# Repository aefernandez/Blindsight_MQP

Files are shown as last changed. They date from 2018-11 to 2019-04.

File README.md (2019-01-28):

# Blindsight MQP

This repository hosts the code for the Blindsight MQP '19. Blindsight is an assistive navigation for the blind. It uses ultrasonic sensors mounted on a pair of 3D printed glasses to detect head-level objects. The device communicates with two vibrating modules using Nordic Semi NRF24 communication modules. The vibrating modules are wrist-worn devices that contain vibrating motors to give an indication of the distance to nearby obstacles. 

MQP - Major Qualifying Project 
Worcester Polytechnic Institute (WPI)

## Getting Started

Visit the Blindsight website and follow the instructions to get started on building your own prototype.

### Prerequisites

In order to program your prototype you'll need to install the Arduino IDE and drivers. The code is written for the ATmega328 platform (UNO, Nano, Mini).

### Installing

Upon downloading the files, place the Blindsight_Library folder inside the Arduino->libraries folder. This will install the Blindsight_Library in your Arduino environment. 

## Authors

* Alan Fernandez      - aefernandez@wpi.edu
* Aatreya Chakravarti - achakravarti@wpi.edu

## License

This project is licensed under the MIT License - see the [LICENSE.md](LICENSE.md) file for details

## Acknowledgments

* Professor Stephen J. Bitar
* Petra Hartman

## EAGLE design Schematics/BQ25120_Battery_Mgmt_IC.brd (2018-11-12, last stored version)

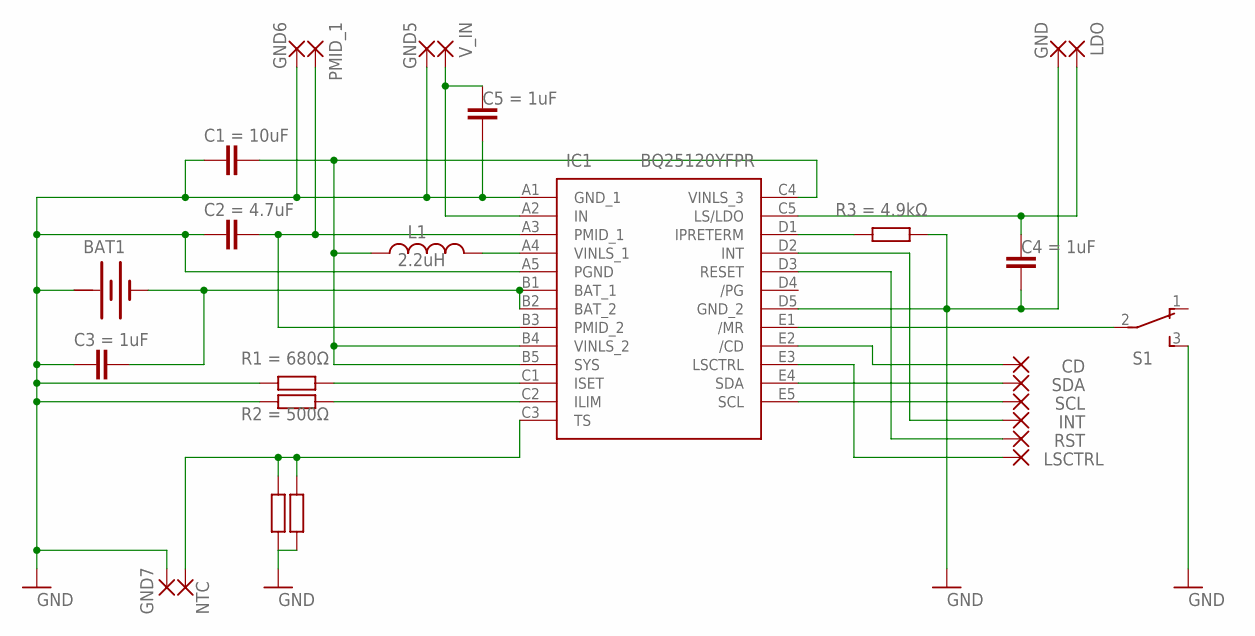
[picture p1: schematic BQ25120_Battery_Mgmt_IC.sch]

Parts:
BAT1: BATTERY
CD: SMD2; SMD1,27-2,54
GND, GND5, GND6, GND7: SMD2; SMD1,27-2,54
IC1: BQ25120YFPR; BGA25C40P5X5_247X253X50
INT: SMD2; SMD1,27-2,54
L1: L-USL2012C; L2012C
LDO: SMD2; SMD1,27-2,54
LSCTRL: SMD2; SMD1,27-2,54
NTC: SMD2; SMD1,27-2,54
PMID_1: SMD2; SMD1,27-2,54
RST: SMD2; SMD1,27-2,54
S1: TL36PO; TL3XPO
SCL: SMD2; SMD1,27-2,54
SDA: SMD2; SMD1,27-2,54
V_IN: SMD2; SMD1,27-2,54

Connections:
+: BAT1.+@1 (+)
GND: BAT1.+, GND.1, GND5.1, GND6.1, GND7.1, IC1.A1 (GND_1), IC1.A5 (PGND), IC1.D5 (GND_2), S1.3 (S)
unnamed: IC1.A4 (VINLS_1), L1.2
unnamed: IC1.E1 (/MR), S1.2
unnamed: BAT1.-, IC1.B1 (BAT_1), IC1.B2 (BAT_2)
unnamed: IC1.B4 (VINLS_2), IC1.B5 (SYS), IC1.C4 (VINLS_3), L1.1
unnamed: IC1.A2 (IN), V_IN.1
unnamed: CD.1, IC1.E2 (/CD)
unnamed: IC1.E4 (SDA), SDA.1
unnamed: IC1.E5 (SCL), SCL.1
unnamed: IC1.D2 (INT), INT.1
unnamed: IC1.D3 (RESET), RST.1
unnamed: IC1.E3 (LSCTRL), LSCTRL.1
unnamed: IC1.C5 (LS/LDO), LDO.1
unnamed: IC1.C3 (TS), NTC.1
unnamed: IC1.A3 (PMID_1), IC1.B3 (PMID_2), PMID_1.1

Board: 2 copper layers, 18 parts (0 on the bottom side), 15 nets, no tracks yet.

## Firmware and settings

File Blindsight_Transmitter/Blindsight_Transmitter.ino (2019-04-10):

/*
Test code for Blindsight: Ultrasonic.
This code controls the Blindsight Assistive Device. It pulses a number of ultrasonic sensors and relays the distance information to vibrating
motors. The vibrating motors are controlled independently and receive the intensity information through a communication module.

Notes:
* This Version Implements:
* * Distance Ranging
* * Temperature Recalibration
* * Distance-Based Vibration Intensity
* * Wireless Comms
* * Device Pausing
* * Friendly Adjustments to Intensity and Sensitivity

Engineers: Alan Fernandez, Aatreya Chakravarti
Date: 03/26/2019
Worcester Polytechnic Institute (WPI)
Blindsight MQP '19

Sources used to write this code are listed below:
* NRF24L01 Implementation:            http://maniacbug.github.io/RF24/starping_8pde-example.html
*                                     https://medium.com/@benjamindavidfraser/arduino-nrf24l01-communications-947e1acb33fb
* Properly Building Arduino Library:  https://www.teachmemicro.com/create-arduino-library/
* MaxBotix Ultrasonic Sensor Setup:   https://www.maxbotix.com/tutorials1/031-using-multiple-ultrasonic-sensors.htm
* TMP36 Datasheet:                    https://www.analog.com/media/en/technical-documentation/data-sheets/TMP35_36_37.pdf
* Adafruit TMP36 Notes:               https://learn.adafruit.com/tmp36-temperature-sensor/using-a-temp-sensor
* Low Power Mode:                     https://learn.sparkfun.com/tutorials/reducing-arduino-power-consumption/all
*/

/*******************************************/
/*** * Hardware Connection Definitions * ***/
/*******************************************/

int PAUSE_PIN       = 3;    // START/PAUSE button
int MOSFET_TRIGGER  = 4;    // MOSFET that powers Ultrasonic Sensors  
int SENSOR_PIN_ONE  = 5;    // Reads pulse from sensor 1
int SENSOR_PIN_TWO  = 6;    // Reads pulse from sensor 2
int CE_PIN          = 7;    // nRF24 Chip Enable Pin
int CSN_PIN         = 8;    // nRF24 Chip Select Pin
int TRIGGER_PIN_1   = 9;    // Used to trigger Sensor1 ranging
int TRIGGER_PIN_2   = 10;   // Triggers Sensor2 ranging
int TEMP_SENSOR_PIN = 14;   // Connected to the temperature sensor
int INTENSITY_POT   = 15;   // Adjusts Intensity
int SENSITIVITY_POT = 16;   // Adjusts Sensitivity


/*********************/
/*** * DEBUGGING * ***/
/*********************/

const char *timed_function_names[5] = {"start_ranging()", "read_sensor()", "print_sensor_datal()",
                                       "calculate_motor_intensity()", "update_nodes()"};
long timed_function_times[] = {0,0,0,0,0};

/* Precompiler Directives to exclude the parts of the code labeled false. Used for debugging. */
#define WIRELESS      true
#define RECALIBRATION false
#define USERINPUT     true

/***************************/
/*** * Library Imports * ***/
/***************************/

/* Import the necessary libraries to handle the Ultrasonic or Time of Flight (TOF) sensors and other support functions. */
#include <SPI.h>
#include <library.h>
#include <printf.h>
#include "RF24.h"
#include "nRF24L01.h"
#include "LowPower.h"

Blindsight_Library BS;

/****************************/
/*** * Global Variables * ***/
/****************************/

int sensorList[]          = {SENSOR_PIN_ONE, SENSOR_PIN_TWO};   // Contains hwd pins associated to each sensor
int intensityList[]       = {0,0};                              // Contains current intensity level for the corresponding motor
int intensity_bool_list[] = {0,0};                              // Contains a flag (1) if the assigned intensity has changed
float pulseList[]         = {0,0};                              // Contains the actual pulses collected from the sensors

unsigned long button_last_read = millis();                      // last time buttons were polled
unsigned long last_temp_check = millis();                       // last time ambient temp was checked

float calibration_temperature = 0;                              // temperature at which device last calibrated

int delta_intensity = analogRead(INTENSITY_POT);                // Offset for the intensity. This number is subtracted from the intensity for each intensity bucket.
                                                                // Refer to USER INPUT section below for more information.
int delta_sensitivity = analogRead(SENSITIVITY_POT);

bool blindsight_running = true;

/********************************/
/*** * Communications Setup * ***/
/********************************/

#if WIRELESS

// Simple integer array to store node data { node_id, returned_data }
int remoteNodeData[2][2] = {{1, 1}, {2, 2}};

// setup radio pipe addresses for each sensor node
const byte nodeAddresses[2][5] = {
    {'N', 'O', 'D', 'E', '1'},
    {'N', 'O', 'D', 'E', '2'},
};

// set transmission cycle send rate - in milliseconds
#define SEND_RATE 1000
unsigned long lastSentTime = millis();
int masterSendCount = 1;

/* Create an NRF24 object */
RF24 radio(CE_PIN, CSN_PIN);
#endif


void setup() {
  Serial.begin(115200);
  pinMode(PAUSE_PIN, INPUT);
  pinMode(SENSOR_PIN_ONE, INPUT);
  pinMode(SENSOR_PIN_TWO, INPUT);

  pinMode(CE_PIN, OUTPUT);
  pinMode(CSN_PIN, OUTPUT);

  #if USERINPUT 
  //pinMode(PAUSE_PIN, INPUT_PULLUP);
  //attachInterrupt(1, PAUSE_ISR, LOW); // attach hardware interrupt to pause pin on falling edge
  #endif

#if WIRELESS
  
  radio.begin();                    // begin radio object
  radio.setPALevel(RF24_PA_LOW);   // set power level of the radio
  radio.setDataRate(RF24_2MBPS);    // set RF datarate - lowest rate for longest range capability
  radio.setChannel(0x76);           // set radio channel to use - ensure all slaves match this
  radio.enableAckPayload();         // enable ack payload - each slave replies with sensor data using this feature
  printf_begin();
  radio.printDetails();             // Dump the configuration of the rf unit for debugging

/* Comms Config Done */
#endif
}

/*********************/
/*** * Main Loop * ***/
/*********************/

void loop() {
  // Do not allow the system to run until both modules are online
  //BS.check_modules_online();
  unsigned long last_pause = millis();
  bool pause_interrupt_set = false;
  
  while(blindsight_running){
    // Before re-attaching the interrupt to the PAUSE Pin:
    // Wait for 5 seconds and make sure the button is not being held down
    if(millis() - last_pause > 5000 && !pause_interrupt_set && digitalRead(PAUSE_PIN) == HIGH){
      attachInterrupt(1, PAUSE_ISR, LOW);
      pause_interrupt_set = true;
    }

    Serial.println("read");
    BS.read_sensor();
    Serial.println("Print");
    BS.print_sensor_data();
    Serial.println("calculate");
    BS.calculate_motor_intensity();
    Serial.println("update");
  #if WIRELESS
    BS.update_nodes();
  #endif
  
/*************************/
/*** * Recalibration * ***/
/*************************/
  
    // Ambient temperature is verified every TEMP_CHECK_INTERVAL minutes to determine if recalibration is necessary.
    // If abs(last_calibration_temperature - current_ambient_temperature) >= 5C then, according to MaxBotix, calibration is necessary.
  #if RECALIBRATION
    if (millis() - last_temp_check > TEMP_CHECK_INTERVAL) {
      //Serial.println("(temp) *** Temperature Check Running ***");
      //Serial.print("(temp) Last calibration temperature: ");
      //Serial.print((temp) calibration_temperature);
      //Serial.println("");
      if (BS.checkTemperature()) {
        //Serial.println("(temp) Recalibration necessary");
        BS.recalibrate_sensors();
        //Serial.println("(temp) Sensor recalibrated");
        delay(100);
      }
      last_temp_check = millis();
    }
  #endif
  
/**********************/
/*** * User Input * ***/
/**********************/
    
  #if USERINPUT
    /* Sensitivity and Intensity Adjustments
     * These globals offset the default intensity/sensitivity setting of the device. 
     * Sensitivity  refers to the distance at which the device begins to consider objects a threat (vibration begins).
     * Intensity    refers to the strength with which the motors vibrate.
     */
     
    // Sensitivity Pot
    // While the sensitivity is being adjusted, ignore all mid and low range readings and only vibrate for the max range. 
    // This should make it easier to select the range of the device. 
    if(abs(delta_sensitivity - analogRead(SENSITIVITY_POT)) > 6){
      unsigned long last_adjust_time = millis();
      
      while(millis() - last_adjust_time < 2000){
        int temp_sensitivity = analogRead(SENSITIVITY_POT);
        
        // if a change is made, reset the last_adjust time
        last_adjust_time = abs(delta_sensitivity - temp_sensitivity) > 6 ? millis() : last_adjust_time;

        // update past sensitivity setting 
        delta_sensitivity = abs(delta_sensitivity - temp_sensitivity) > 6 ? temp_sensitivity : delta_sensitivity;

        // calculate intensity and ignore the MID and LOW range obstacles - only vibrate for objects at the MAX range
        BS.calculate_motor_intensity(true);
        BS.update_nodes();
      }
    }
   //delta_sensitivity = analogRead(SENSITIVITY_POT);
   
    Serial.print("Sensitivity: ");
    Serial.println(delta_sensitivity);
    // Intensity Pot
    // Detect if user changed potentiometer. If he did then begin intensity adjustment.
    // This means vibrating the bands continuously so that the intensity may be set more easily
    // Stop the continuous vibrations after 2 seconds
    if(abs(delta_intensity - analogRead(INTENSITY_POT)) > 6){
      unsigned long last_adjust_time = millis();

      // stay in adjustment mode until the potentiometer value is not changed for >2seconds
      while(millis() - last_adjust_time < 2000){
        // read in intensity setting
        int temp_intensity = analogRead(INTENSITY_POT);
        
        // if a change is made, reset the last_adjust time
        last_adjust_time = abs(delta_intensity - temp_intensity) > 6 ? millis() : last_adjust_time;
        
        // update past intensity setting
        delta_intensity = abs(delta_intensity - temp_intensity) > 6 ? temp_intensity : delta_intensity;
        
        // send packet to bands to vibrate at new intensity at min period
        // activate the override parameter and use the default period
        int scaled_intensity = 255 - ((float)delta_intensity-0)/(1023-0)*255;

        // update the nodes 
        BS.update_nodes(true, scaled_intensity);
        Serial.print("Intensity: ");
        Serial.println(delta_intensity);
      }

      // reset the vibration setting at the nodes 
      BS.update_nodes(true, 0); 
    }


  #endif
  }

  /**************************/
  /*** * LOW POWER MODE * ***/ 
  /**************************/
  //Serial.println("Entering Low Power Mode");
  #if USERINPUT
    low_power_mode();
    blindsight_running != blindsight_running;
    //Serial.println("Exit Low Power Mode");
  #endif
}

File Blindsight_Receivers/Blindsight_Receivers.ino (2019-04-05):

///*
//Test code for Blindsight: Ultrasonic Receivers.
//This code controls the Blindsight Assistive Device. It pulses a number of ultrasonic sensors and relays the distance information to vibrating
//motors. The vibrating motors are controlled independently and received the intensity information through a communication module.
//
//Notes:
//* This Version Implements:
//* * Distance Ranging
//* * Temperature Recalibration
//* * Distance-Based Vibration Intensity
//* * Wireless Comms
//*
//* Not Implemented Yet:
//* * Reduction of Global Variables (for good practice)
//
//Authors: Alan Fernandez, Aatreya Chakravarti
//Date: 12/13/2018
//Worcester Polytechnic Institute (WPI)
//Blindsight MQP '19
//
//Sources used to write this code are listed below:
//* NRF24L01 Implementation:            http://maniacbug.github.io/RF24/starping_8pde-example.html
//*                                     https://medium.com/@benjamindavidfraser/arduino-nrf24l01-communications-947e1acb33fb
//* Properly Building Arduino Library:  https://www.teachmemicro.com/create-arduino-library/
//* MaxBotix Ultrasonic Sensor Setup:   https://www.maxbotix.com/tutorials1/031-using-multiple-ultrasonic-sensors.htm
//* TMP36 Datasheet:                    https://www.analog.com/media/en/technical-documentation/data-sheets/TMP35_36_37.pdf
//* Adafruit TMP36 Notes:               https://learn.adafruit.com/tmp36-temperature-sensor/using-a-temp-sensor
//*/
//
//
#include <SPI.h>
#include <RF24.h>
#include <nRF24L01.h>
#include <printf.h>
#include "LowPower.h"

// chip select and RF24 radio setup pins
#define CE_PIN            7
#define CSN_PIN           8
#define MOTOR_PIN         6   // Motor 2 output
#define NODE_ID           0   // set to the appropriate number (0, 1, 2)

RF24 radio(CE_PIN,CSN_PIN);

uint8_t* pipe_num;  // Pipe in which the message is received

// setup radio pipe addresses for each slave node
const byte nodeAddress[2][5] = {
    {'N','O','D','E','1'},
    {'N','O','D','E','2'},
};

// simple integer array for each remote node data, in the form [node_id, returned_count]
int remoteNodeData[2][2] = {{1, 1,}, {2, 1}};

// integer to store count of successful transmissions
int dataFromMaster = 0;

// sleep mode flag
bool sleep_mode = false;

int pwm_setting = 0;
float previous_period = 0;
float period = 1;
float period_ms = 0;
unsigned long start_t;
unsigned long end_t;
float interrupts_per_period = 0;
int   number_of_interrupts = 0;
bool vibrate_on;
/* Function: setup
 *    Initialises the system wide configuration and settings prior to start
 */
void setup() {
  pinMode(3, OUTPUT);
  pinMode(4, OUTPUT);
  pinMode(MOTOR_PIN, OUTPUT);
  // configure timer 2 to ~16ms interrupt
//  TIMSK2 = (TIMSK2 & B11111110) | 0x01;
//  TCCR2B = (TCCR2B & B11111000) | 0x07;
  
  // setup serial communications for basic program display
  Serial.begin(115200);
  Serial.println("[*][*][*] Beginning nRF24L01+ ack-payload slave device program [*][*][*]");

  // ----------------------------- RADIO SETUP CONFIGURATION AND SETTINGS -------------------------//

  radio.begin();
  radio.setPALevel(RF24_PA_HIGH);          // set power level of the radio
  radio.setDataRate(RF24_2MBPS);          // set the transmit rate
  radio.setChannel(0x76);                 // set radio channel to use - ensure all slaves match this
  radio.openReadingPipe(1, nodeAddress[NODE_ID]);
  //radio.setAutoAck(1);                  // Ensure autoACK is enabled
  radio.enableAckPayload();               // Allow optional ack payloads
  radio.writeAckPayload(1, &remoteNodeData[NODE_ID], sizeof(remoteNodeData[NODE_ID]));
  //radio.setRetries(0, 3);                 // Smallest time between retries, max no. of retries
  printf_begin();
  radio.printDetails();                   // Dump the configuration of the rf unit for debugging
  radio.startListening();
  // --------------------------------------------------------------------------------------------//

  
  // configure the timer to trigger when the count is 0xFF (0'd255).
  configure_interrupt();
}

void loop() {
  // transmit current preloaded data to master device if message request received
  while(!sleep_mode){
    radioCheckAndReply();
  }
  Serial.println("Entering Low Power Mode");
  //low_power_mode();
  sleep_mode = false;
  
}

/* Function: updateNodeData
 *    updates the count variable for the node and stores it in the nRF24L01+ radio
 *    preloaded ack payload ready for sending on next received message
 */
void updateNodeData(void){
  // increment node count - reset to 1 if exceeds 500
  if (remoteNodeData[NODE_ID][1] < 500) {
    remoteNodeData[NODE_ID][1]++;
  } else {
    remoteNodeData[NODE_ID][1] = 1;
  }
  // set the ack payload ready for next request from the master device
  radio.writeAckPayload(1, &remoteNodeData[NODE_ID], sizeof(remoteNodeData[NODE_ID]));
}


/* Function: radioCheckAndReply
 *    sends the preloaded node data over the nrf24l01+ radio when
 *    a message is received by the master
 */
void radioCheckAndReply(void){
  start_t = millis();
//  Serial.println(period);
//  Serial.println(vibrate_on);
  // check for radio message and send sensor data using auto-ack
  if ( radio.available()) {
    digitalWrite(4, HIGH);
    radio.read( &dataFromMaster, sizeof(dataFromMaster) );
    Serial.println("Received request from master - sending preloaded data.");
    Serial.print("The received count from the master was: ");
    Serial.println(dataFromMaster);
    Serial.print("Received from Pipe: ");
    Serial.println(*pipe_num);
    Serial.print("Reading from pipe: ");
    Serial.println("");
    Serial.println("--------------------------------------------------------");
    // obtain the period. The first 3 digits correspond to the PWM value, the last is the period divisor.
    // ie. 2554 -> PWM: 255, Period: 1/4
    
    period = 1.0 / (dataFromMaster % 10);
    period_ms = period * 1000;
    pwm_setting = (dataFromMaster - (dataFromMaster % 10)) / 10;
    vibrate_on = (period != 1)?true:false;
    
    //Serial.print("Received PWM: ");
//    Serial.println(pwm_setting);
//    Serial.print("Received Period: ");
//    Serial.println(period);
    
    if(dataFromMaster == 9999){
      analogWrite(MOTOR_PIN, 0);
      sleep_mode = true;
    }

    // removes the delay for the first pulse
    if(period != previous_period && period != 1.0){
      analogWrite(MOTOR_PIN, (pwm_setting > 105)?pwm_setting : 105);
      digitalWrite(3, HIGH);
      previous_period = period;
    }
    
    // update the node count after sending ack payload - provides continually changing data
    updateNodeData();
  }
//  Serial.print("time for all: ");
//  Serial.println(millis() - start_t);
  // this is for the logic analyzer
  digitalWrite(4, LOW);
}
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

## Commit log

2018-11-12 Ultrasonic V1
    Arduino code for the ultrasonic version of the Blindsight MQP. This version contains working code to poll the ultrasonic sensors and untested code for temperature compensation as well as vibrating motor control.
2018-11-12 BQ25120 Circuit
    First rendition of the BQ25120 schematic. The PCB is not ready in this version.
    [BQ25120_Battery_Mgmt_IC.brd, BQ25120_Battery_Mgmt_IC.sch]
2018-11-28 BQ51013a Altium Files
    Schematic mostly completed.
    [BQ51013a_Circuit.PcbDoc, BQ51013a_Schematic.SchDoc]
2018-12-07 vl53l0x code
    vl53l0x arduino mega code
2018-12-07 vl53l0x code
    instantiate new objects for each sensor
2018-12-11 Ultrasonic Library
    Added the library for the ultrasonic sensors. It contains the functions to handle both the ultrasonic sensor specific tasks and the general Blindsight tasks.
2018-12-12 Compensated Ultrasonic Code
    Compensation of sensorList[] function done
    [BQ51013a.PcbDoc, BQ51013a.SchDoc, BQ51013a_Circuit.PcbDoc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]
2018-12-13 Vibration Intensity Buckets Added
    Added vibration intensity buckets to the code. The buckets are set for demo meaning that the ranges they group are much shorter than necessary for real world operation.
2018-12-13 Temperature Based Recalibration Implemented
    This version includes the necessary code for temperature recalibration.
2018-12-13 Sensor Power MOSFET Added
    This version contains the necessary code to switch off the sensors during temperature calibration.
2018-12-14 Schematics and Code Updates
    Minor updates in the code. Mostly formatting. Schematics for the B Term report were added.
    [PWM_Circuit.SchDoc, Sensor_Recalibration_Circuit.SchDoc]
2018-12-16 Original GIT Schematics
    Schematics for originally-selected power modules
2019-01-12 Motor_PWM_Testing
    Single motor testing with different pwm duty cycles via a potentiometer
2019-01-24 Sleep Mode, Updated Libraries
    Additions:
    -Master waits for slaves to report before allowing the device to begin working
    -Push button on master triggers sleep mode on slaves and master
    -Slaves enter sleep mode with timeout. Poll every 8s for wake up signal.
    Notes:
    -Sleep mode in the master remains untested.
    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
2019-01-27 Sleep Mode Master Fixes
    Fixed bug that kept master from waking up from sleep mode. A print statement inside the PAUSE_ISR seems to have been the culprit.
    [Arduino_Blindsight.ino, Blindsight_Receivers.ino]
2019-01-28 Comments, Formatting...
    Added comments, fixed formatting, made code generally prettier.
    [Arduino_Blindsight.ino]
2019-03-21 Improvements
    This version removes the lag between sensing an object and vibrating the bands. The lag is resolved by manually triggering each sensor rather than depending on the automatic triggering offered by the sensors. A rolling average is also applied to increase sensitivity to objects at a close range that enter the FOV suddenly.
    [Arduino_Blindsight.ino, Blindsight_Receivers.ino]
2019-04-05 Intensity Adjustment Friendliness
    The device now vibrates constantly while the intensity is being adjusted. This allows for the user to more easily select the desired intensity level.
    [Arduino_Blindsight.ino, Blindsight_Receivers.ino]
2019-04-05 Intensity Adjustment Friendliness
    The device now vibrates constantly while the intensity is being adjusted. This allows for the user to more easily select the desired vibration intensity.
2019-04-10 Removed Irrelevant Testing Code
    Removed sample test code for the TOF sensor.
2019-04-10 Repository Cleanup
    Removed imcomplete testing codes and old schematics and renamed files for consistency.
    [BQ25120_Battery_Mgmt_IC.brd, BQ25120_Battery_Mgmt_IC.sch, BQ51013a.PcbDoc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]
